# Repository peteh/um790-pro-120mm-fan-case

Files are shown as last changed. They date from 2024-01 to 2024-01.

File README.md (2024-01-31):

# Minisforum UM790 Pro 120mm Fan Body

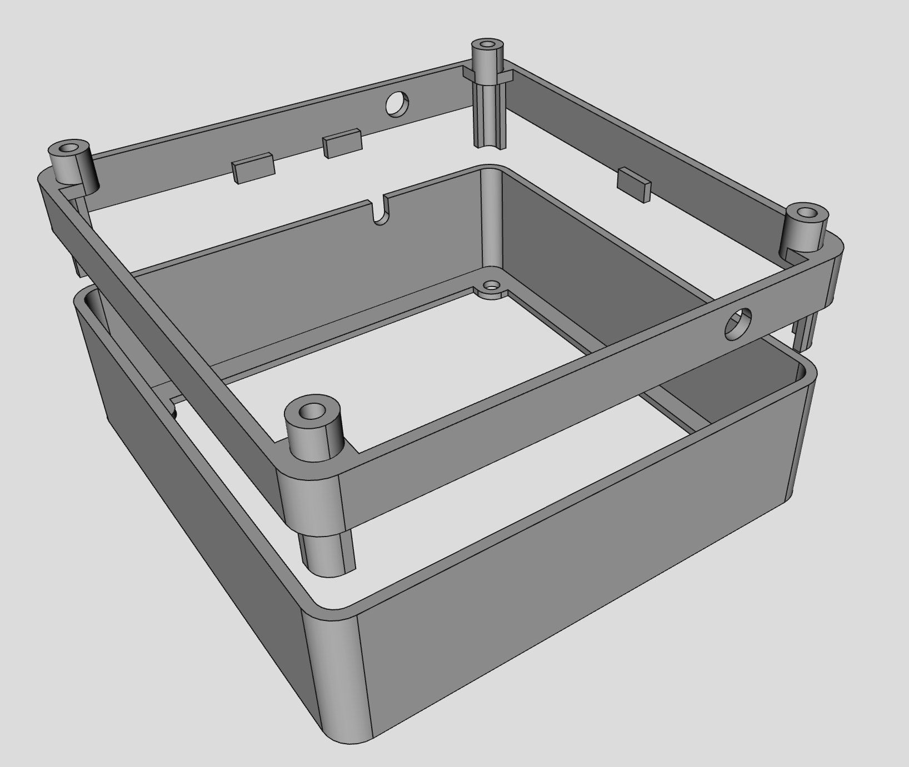
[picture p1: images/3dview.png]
3D View


This is a fan case for Minisforum UM790 pro with ports for external antennas. As the internal fan for SSD and Memory seems to often fail and has a pretty bad temperature curve without a proper hysteresis I decided to replace it with a 120mm fan as it kinda fits with the size of the mini PC.

It consists of two parts. One to house the fan and another one to mount to the top and hold the two antennas.

The fan itself connects via a USB cable to one usb port on the back of the mini PC. You can use pretty much any 120mm fan that connects via usb. I additionally added a filter to not suck dust into the PC.

## Assembly

### Top Part Assembly

1. Print both of the parts. I printed them on a Bambu Labs P1C with default settings. The top part needs support (I enabled Tree supports which turned out fine)
2. Screw the sma connectors of the two antennas into the 2 holes in the top part on the left and right side
3. Remove the bottom lid of the UM790 - be careful with the cables
4. Unplug the original fan
5. Remove the WiFi card screw and slide off the plastic cover
6. Attach the two mini connectors to the WiFi card (I did it outside of the case on a flat surface - it was easier)
7. Attach the WiFi card back into the case
8. Try to find resonable place for the cables so that they cannot hang downwards when the bottom part is assembled so they don't touch the fan later
9. Use the 4 original screws to to fit the top part onto the UM790 pro

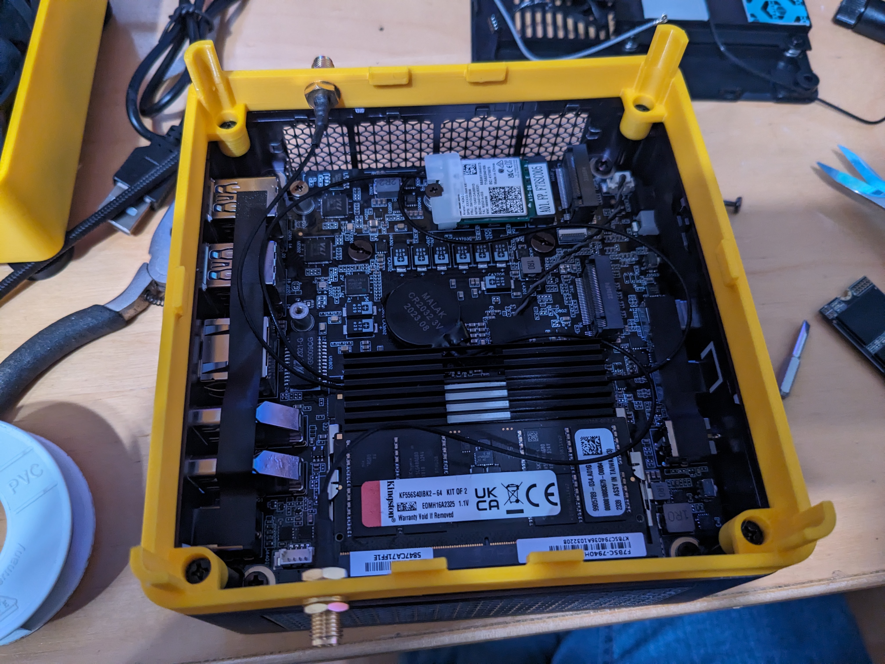
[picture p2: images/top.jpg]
Top Part


### Bottom Part Assembly

1. First put the filter into the case
2. Put the fan into the case so the fan direction will push air into the case
3. From the outside, put the fan grill and screw the feet into the fan through the 4 holes of the 3d printed bottom case part

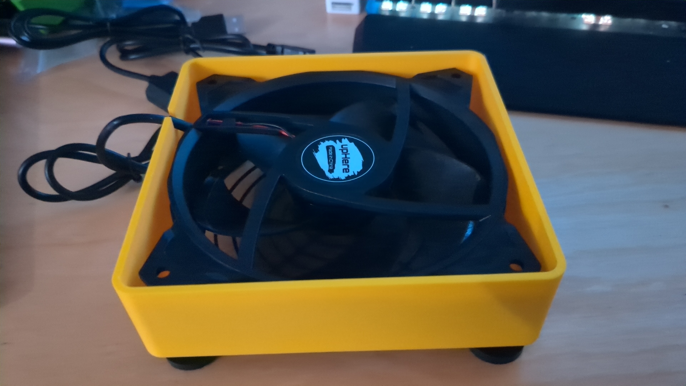
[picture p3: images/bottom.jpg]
Bottom Part


### Final Assembly

1. Put the top part with the UM790 onto the bottom part so they slide into each other
2. attach the two antennas on the sides

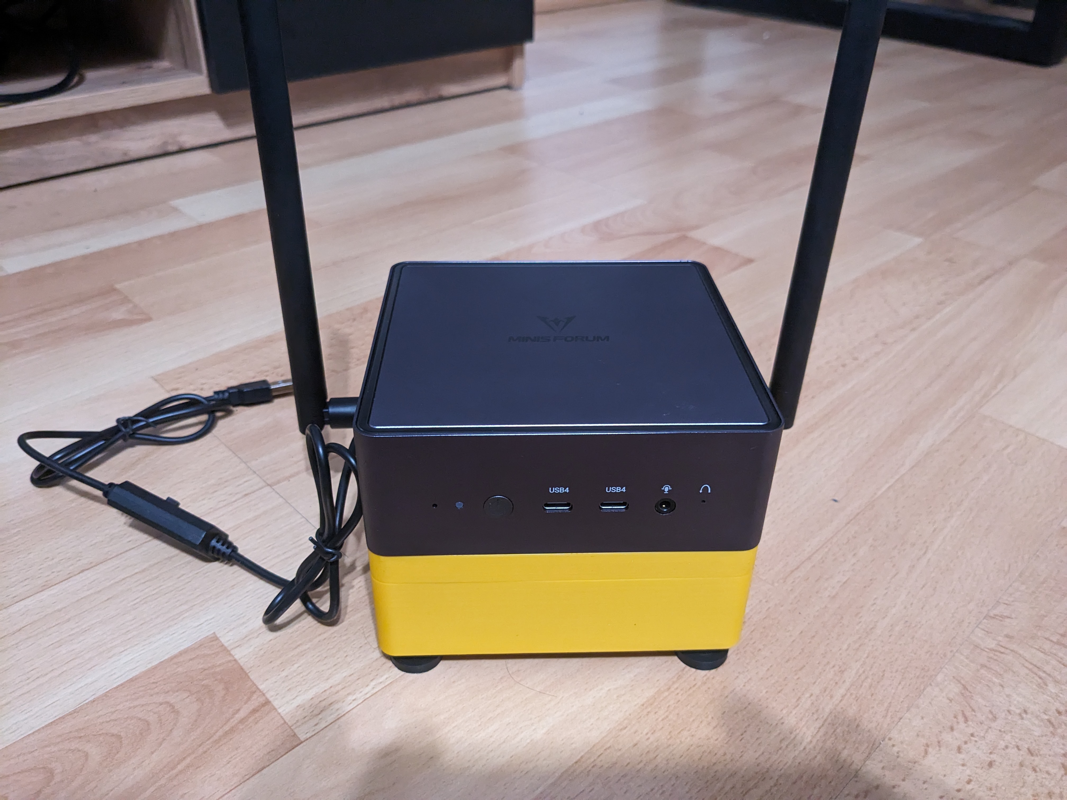
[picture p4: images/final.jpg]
Final Assembly


## Parts

### 120mm USB Fan

A 120mm fan that you can connect via USB.

Here are some ideas:

- USB Fan with rubber feet : [Buy on Amazon (partner link)](https://amzn.to/3RZcTu3)
- Noctua 120mm USB fan: [Buy on Amazon (partner link)](https://amzn.to/3SlVcFB)

### Dust filter for 120mm fans

Optional: A dust filter that stops the fan from pulling in dust particles from the bottom.

[Buy on Amazon (partner link)](https://amzn.to/41W7HvQ)

### External Antennas

External antennas to connect Bluetooth and WiFi because the original antennas are embedded into the bottom case lid.

Amazon.de: [Buy on Amazon (partner link)](https://amzn.to/47tY6NS)

## Credits

Project inspiration: <https://sagar.se/blog/um790-cooling-wifi/>

## Further Links

Thingiverse: <https://www.thingiverse.com/thing:6432671>

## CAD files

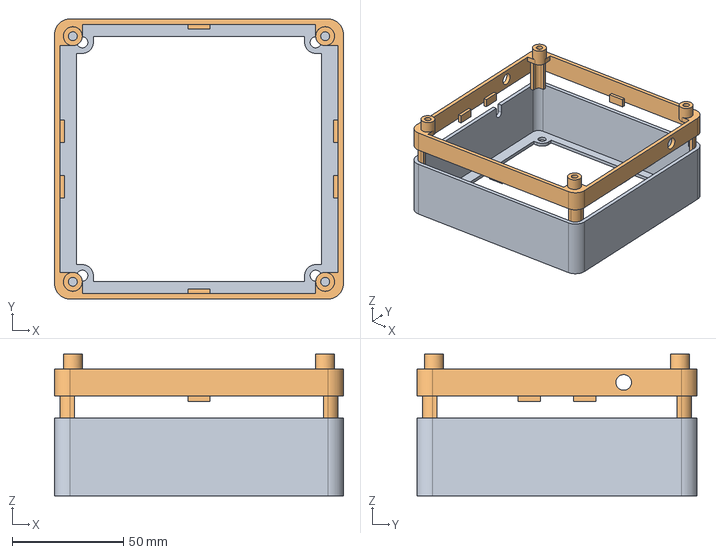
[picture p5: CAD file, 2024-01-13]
freecad/case.FCStd
130.0 x 126.0 x 63.7 mm
Bottom
Top

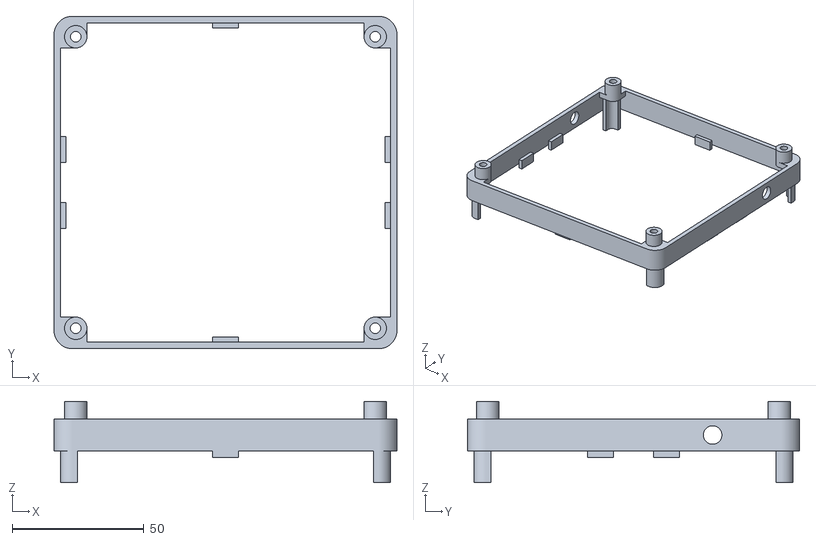
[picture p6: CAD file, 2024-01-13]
stl/case-Top.stl
130.0 x 126.0 x 30.7

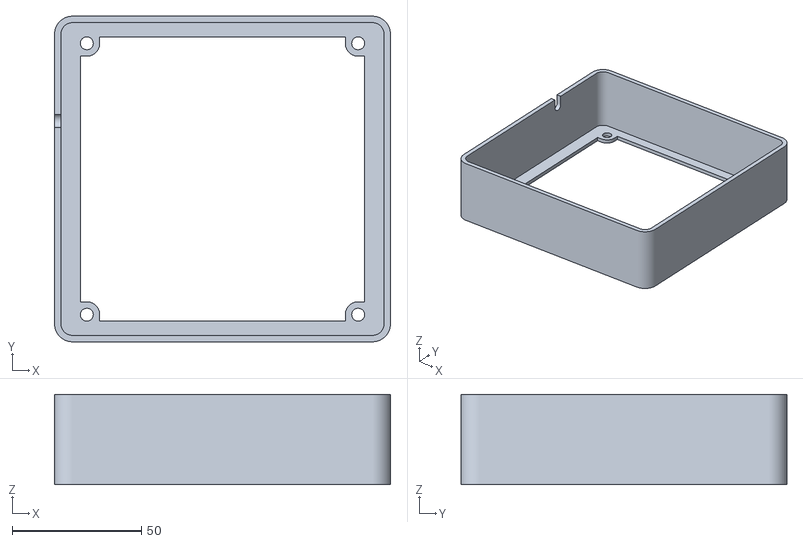
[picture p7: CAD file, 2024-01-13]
stl/case-Bottom.stl
130.0 x 126.0 x 35.0

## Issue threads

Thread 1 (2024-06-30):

3d print material

Hagstrom82, 2024-06-30:
Hello, I chose PETG for printing, but it may not be the best material. The smaller piece tends to bend, and it doesn't line up properly with the larger piece.
Is there a preferred printing material for this type of use, perhaps more rigid ?

peteh, 2024-07-01:
I used PLA printed on a bambulab. Can you take and pictures?

Hagstrom82, 2024-07-01:
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

Hagstrom82, 2024-07-01:
Unfortunately I don't have a 3D printer, I used the Craftcloud service. That's why I asked you if there was a stiffer material, I could then order a new print only for the part concerned.

peteh, 2024-07-02:
You could  use some stiffer plastic, e.g. from packaging and glue it to the bottom part on the inside if you are ok with a bit of diy. Then this would hold the top part in place. I think this is a structural issue that has to be otherwise solved in the model as the antennas put a bit of pressure with a lever effect which will result in warping a bit.

I probably have to add a better frame that goes around the whole thing instead of just the corners.

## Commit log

2024-01-13 ADD: 3d files
    [case-Bottom.stl, case-Top.stl, case.FCStd]
2024-01-16 ADD: link for noctua fan
